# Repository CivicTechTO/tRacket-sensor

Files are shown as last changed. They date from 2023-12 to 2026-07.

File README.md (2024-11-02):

# tRacket: Community-Driven Urban Noise Monitoring

This repository contains all source code and hardware design files for the [tRacket](https://tracket.info/) noise sensor.

## Overview

Environmental noise, especially in urban settings, is a [known public health concern](https://www.toronto.ca/wp-content/uploads/2017/11/8f98-tph-How-Loud-is-Too-Loud-Health-Impacts-Environmental-Noise.pdf):

> The growing body of evidence indicates that exposure to excessive environmental
noise does not only impact quality of life and cause hearing loss but also has other health impacts, such as cardiovascular effects, cognitive impacts, sleep disturbance and mental health effects.

The tRacket noise sensor continuous monitors ambient sound levels (in [decibels](https://en.wikipedia.org/wiki/Decibel), dBA) and sends these measurements to an [online dashboard](https://dashboard.tracket.info/locations) ([also on GitHub](https://github.com/CivicTechTO/tRacket-dashboard)). Our goal is to help local communities better understand the sound levels and extreme noise events that they experience day to day.

The project has been started and is maintained by volunteers from the [CivicTech Toronto](http://www.civictech.ca) community.

## Privacy

We followed Privacy by Design principles in setting up the data collection. 

1. The sound meter devices are deployed on private properties in residential areas at different locations in the city. We are **not publishing exact device locations**. 
2. The devices **do not record sound** only sound levels in A-weighted decibel levels (dBA)(https://en.wikipedia.org/wiki/Decibel). 
3. We calculate minimum and maximum sound levels at 5 minute intervals on the device and **only broadcast these aggregate values** (along wiht the device ID) to a database.

## Source Code

The [noisemeter-device](/noisemeter-device) folder contains the device's source code, which is written in C++ and can be built using [PlatformIO](https://platformio.org/). Build instructions are available [in the online documentation](https://civictechto.github.io/tRacket-sensor/md_noisemeter_device_BUILD.html).

The source code is released under the [GNU GPL v3 license](/noisemeter-device/LICENSE).

## Hardware Files

The [hardware](/hardware) folder contains design files and documentation for each iteration of the sensor hardware. The PCBs are designed using [KiCAD](https://www.kicad.org/).

The hardware design files are released under an [open hardware license](/hardware/pcb-rev2/LICENSE).

## For Developers

* Check out the [Issues page](https://github.com/CivicTechTO/tRacket-sensor/issues) to see current bugs and feature requests. Any contributions are welcome!
* Online documentation of the firmware [is available here](https://civictechto.github.io/tRacket-sensor/).

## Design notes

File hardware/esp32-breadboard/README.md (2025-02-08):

# ESP32 Breadboard prototype

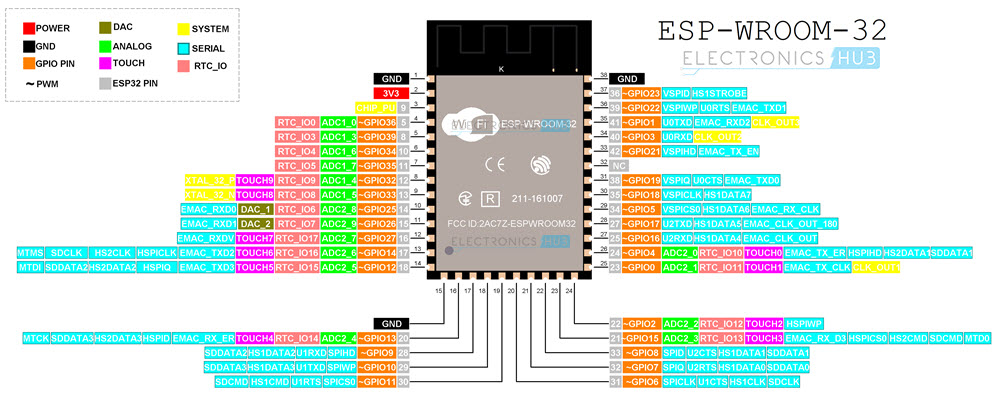
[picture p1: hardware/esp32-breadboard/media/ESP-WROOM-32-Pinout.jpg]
ESP32-WROOM Pinout


Board used (ESP32-WROOM): [https://a.co/d/6XwJp64](https://a.co/d/6XwJp64)

Mic module used (SPH0645LM4H): [https://www.adafruit.com/product/3421](https://www.adafruit.com/product/3421)

## Pin Connections:

| Mic  | Board |
| ---- | ----- |
| GND  | GND |
| BCLK | P23 |
| DOUT | P19 |
| LRCL | P18 |
| SEL  | GND |
| 3V | 3V |

| Misc  | Board |
| ----- | ----- |
| Reset | P5 |

> IMPORTANT - The I2S protocol is a 2-channel data stream. The SEL pin on the mic must be pulled LOW (to GND) in order to work with the example code, which reads data from the RIGHT CHANNEL only. Alternatively, the I2S driver can be set to read from left channel, although it remains unclear whether this would involve tying the SEL pin to 3.3V. If you get no appreciable readings (or all readings are the same as the MIC_NOISE_DB variable) then you may be reading the wrong channel, or you may need to check the SEL pin!

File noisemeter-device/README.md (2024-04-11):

# Noisemeter Device Firmware

This documentation is generated from the firmware's source code files. Modules of functionality are generally organized into classes; see the "Classes" tab to navigate their documentation. Other functions, constants, and variables can be found within the file list or via the search bar.

See "Related Pages" for other relevant documentation including build instructions and deprecated code.

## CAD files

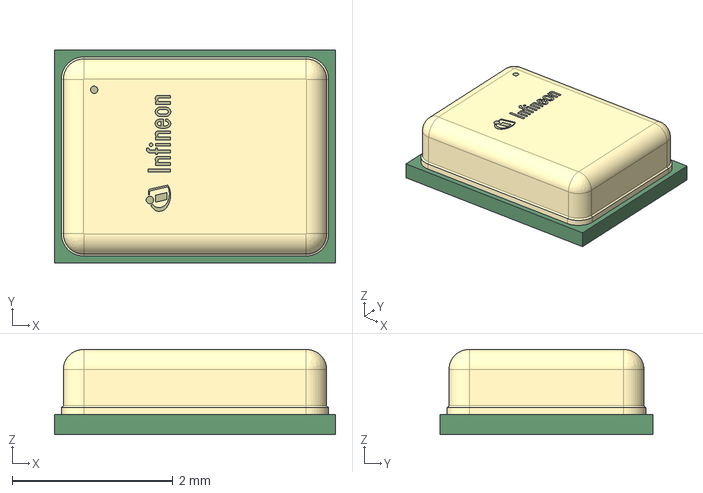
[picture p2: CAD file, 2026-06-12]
hardware/pcb-rev4/PG-TLGA-5-2_Z8B00234305_V05_3D.stp
3.50 x 2.65 x 1.06 mm

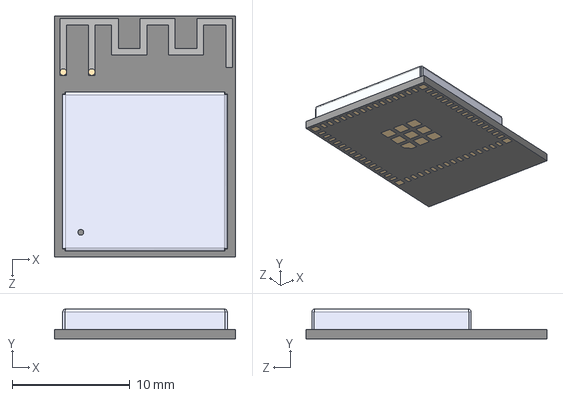
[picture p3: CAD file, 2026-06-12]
hardware/pcb-rev4/ESP32-S3-MINI-1-N8.STEP
15.4 x 2.55 x 20.5 mm

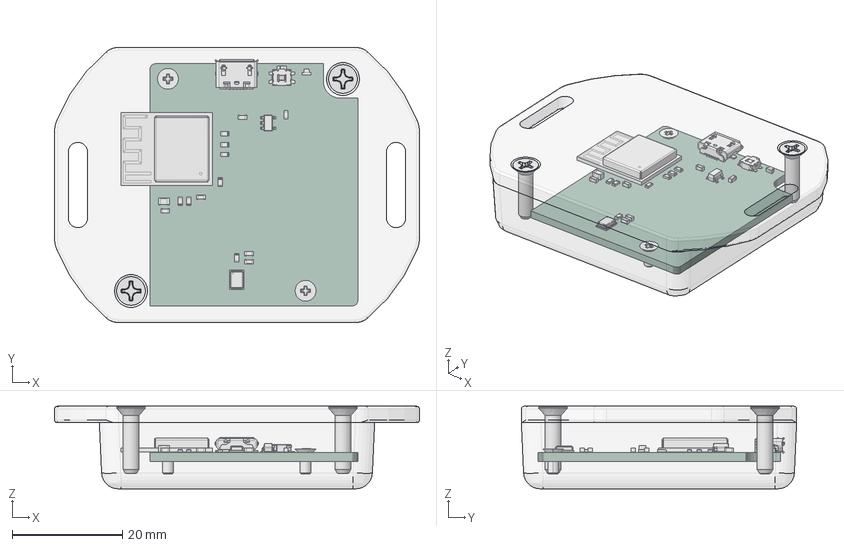
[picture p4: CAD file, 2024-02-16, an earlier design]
hardware/pcb-rev2/nmeter_cased.FCStd
66.3 x 50.0 x 15.0 mm
1551S Box
1551R-S Flange Lid
SC510 (screw #4X 1_2'' FH)
SC510 (screw #4X 1_2'' FH)001
_autosave-noisemeter PCB

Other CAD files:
hardware/pcb-rev3/tracket.FCStd

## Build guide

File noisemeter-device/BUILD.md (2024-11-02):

# Build Instructions

## Source code preparation

1. Save the SSL root certificate to `certs.h` using the following command:
```bash
python certs.py -s api.tracket.info > certs.h
```

## Code compilation and upload

1. [Install PlatformIO](https://platformio.org/install).

2. Run `pio run` to compile for the PCB. A breadboard target is available too: `pio run -e esp32-breadboard`.

3. Run `pio run -t upload` to upload to the device (this also compiles the code if there have been any changes).

## HMAC encryption key

Data stored on the device (e.g. WiFi credentials) are encrypted with an "eFuse" key. This key can only be configured once, and cannot be read or written after that. 

```bash
dd if=/dev/urandom of=hmac_key bs=1 count=32
pio pkg exec -- espefuse.py --port /dev/ttyACM0 burn_key BLOCK4 hmac_key HMAC_UP
rm hmac_key
```

This is done in the `bringup.sh` script that is used to program new sensors.

**Please generate a unique hmac_key for each device.**

## Enable secure download mode

Enabling secure download mode prevents users from using USB/serial download mode to dump memory contents (WiFi credentials and API token):

```bash
pio pkg exec -- espefuse.py --port /dev/ttyACM0 burn_efuse ENABLE_SECURE_DOWNLOAD
```

Then, if new firmware is to be uploaded over USB in the future, upload using this command:

```bash
pio pkg exec -- esptool.py write_flash 0x10000 .pio/build/esp32-pcb/firmware.bin
```

## Signing OTA updates

OTA updates must be signed for deployed tRacket sensors to accept them. The
GitHub repo is configured to automatically sign firmware updates when releases
are published.

Signing requires a 4096-bit RSA key. To sign an update (assuming you have the
private key), run `pio run -t ota`.

The public key is to be stored in `noisemeter_device/ota_update.cpp`. To obtain
the public key (assuming you have the private key), run:

```bash
openssl rsa -in priv_key.pem -pubout > rsa_key.pub
```

## Operation Overview:

* After initial programming or a factory reset, the device will enter Hotspot mode once it is powered on. This is indicated by a blinking LED.
* In Hotspot mode, you can connect to the device's "Noise meter" WiFi network to set it up. Password is "noisemeter".
* Once connected, a captive portal will bring you to a form to enter your WiFi credentials and email for registration. Your credentials will be encrypted and stored to the on-board flash memory.
* After completing the form, the device will reboot and attempt to connect to your WiFi.
* Once connected, the device will sync itself with a NTP time server and then begin taking readings.
* The device takes 100-millisecond audio recordings and instantly converts them to decibel "loudness" values. Each recording is discarded as soon as it is processed.
* Over time, the decibel values are aggregated into minimum, average, and maximum values. Periodically, these values will be uploaded to the server at which point the device will clear its cached data and begin taking a new set of readings.
* To factory reset the device and clear your saved credentials, hold the Reset button while you power on the device until the LED begins blinking.

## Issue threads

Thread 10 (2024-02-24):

Batch data uploading

tcsullivan, 2024-02-24:
The WiFi is intermittent on my balcony, so my device is sometimes unable to upload its latest min/max/average data. Currently we just discard the data point if the upload fails, but instead I think we should keep a list of previous data points that can be uploaded to the server later once the WiFi connection is restored.

The min/max/average data point is only a handful of bytes, so we are probably fine to just keep this list in RAM (*unless* we want to run devices long-term offline and bring them some WiFi every now and then to collect their data, which would require storing to flash). Let's make a list that can store data points that fail to upload and iterate through that list once we can successfully reach the server.

For this to be worthwhile, we'll want to implement #9 first.

tcsullivan, 2024-03-06:
The `timestamp` branch has batch uploading now. Keeps a `std::forward_list` of failed uploads and tries to send them all with each time interval. WiFi seems to reconnect automatically, but we also call `WiFi.reconnect()` before uploads to be safe.

Closed 2024-03-09.

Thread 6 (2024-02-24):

Encryption for stored information

tcsullivan, 2024-02-24:
The device stores the user's WiFi SSID, passkey, and device ID. The API token is in firmware too. Some or all of these should be encrypted for the sake of security.

The `encryption` branch has a simple implementation of AES encryption for the WiFi passkey. It uses the device's ID as an encryption key.

* What info should be encrypted?
* What should the encryption key be? How should the key be stored?

tcsullivan, 2024-03-15:
Let's just encrypt the WiFi credentials and the API token (as that will eventually be device-specific). I'm hoping we can find a hardware encryption feature that will make it difficult to extract these from a device.

tcsullivan, 2024-03-16:
Merged `main` into `encryption` to bring it up to date, and encrypted the SSID.

I don't know if there's anything we can do to make the encryption key truly "secret". The best solution I have is physical: If the reset button is not held down at startup, then immediately disconnect the serial/USB pins by setting pins 18 through 21 to OUTPUT. This way, we could limit a hacker's ability to dump the microcontroller's memory to decrypt our secrets.

tcsullivan, 2024-04-03:
I've discovered that we can use the HMAC with eFuse memory to do this encryption without exposing the key. Working on this now. Might also need to consider secure boot to fully ensure that a user can't extract the key or decrypted data.

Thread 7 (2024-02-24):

Over-the-Air (OTA) Updates

tcsullivan, 2024-02-24:
We want to be able to apply software updates to devices that are already deployed. Ideally, I think this should be automatic and more or less hidden from the user: every day or week check for an update from the server, and just apply it if available.

The `ota-support` branch has a proof-of-concept implemented. Some things to figure out:

* Hosting updates on the project's server
* Versioning of the updates (i.e. having "official" releases of updates)
* Can we sign the updates with a key to verify that they came from our server?
* Are there any other security considerations?

tcsullivan, 2024-03-15:
Let's look into using GitHub as the update host: maybe an Action can generate the latest firmware? An automated release?

How could we keep info on the latest version number...

tcsullivan, 2024-03-15:
I'm thinking too that the update checks should be run daily, as in 24 hours from the device's startup or last check. That will help stagger requests for update downloads.

tcsullivan, 2024-03-15:
Also, we'll want to make a note to update the HTTPS certificates between releases to prevent them from expiring.

tcsullivan, 2024-03-24:
Tested the 24hr timer on a rev2 PCB, it works!

Closed 2024-03-24.

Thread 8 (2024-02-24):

Prevent physical reprogramming

tcsullivan, 2024-02-24:
1. Disable the ESP32's programming interface. Changing the pin modes for the USB/serial pins may be enough; also need to check on bootloader settings. Actually committing to this change will require #7 first.
2. Consider flash encryption or other available options to disable readout. It looks like the ESP32's hardware encryption has [already been circumvented](https://hackaday.com/2024/01/15/breaking-the-flash-encryption-feature-of-espressifs-microcontrollers/), so I'm not sure we should bother with this.

tcsullivan, 2024-03-14:
This was my own idea, but after discussion we've agreed to let the devices be reprogrammable. All we really need to worry about is preventing reading/decrypting of secrets stored on the device.

tcsullivan, 2024-03-15:
Just noting the actual results of [the circumvention](https://courk.cc/breaking-flash-encryption-of-espressif-parts):

* Requires custom hardware and flash emulation to work
* Designed for *external* flash, while the MINI modules we're using are flash-in-chip. Would be much more difficult if not impossible to crack a module with this method.

Closed 2024-03-14.

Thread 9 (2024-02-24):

Generate timestamps on device

tcsullivan, 2024-02-24:
The data samples that get sent to the server should be timestamped on the device at the moment they are calculated, rather than relying on the server to timestamp the data whenever it receives it. Apparently the server already supports receiving timestamps (as a `timestamp` field within the JSON), so this should be easy to implement.

The server is flexible on the format of the timestamp, but let's stick to something standard.

tcsullivan, 2024-03-06:
This functionality is present in the `timestamp` branch now. Adding to the JSON was as easy as expected.

Closed 2024-03-09.

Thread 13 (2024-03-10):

Device setup form styling

tcsullivan, 2024-03-10:
Currently, the device setup form is just a super-simple request for WiFi credentials. Apart from functional improvements (email request, device ID reset option?), the form should also be styled better: colors, fonts maybe, project logo maybe, overall prettier presentation, and probably some user instructions/info.

The post-submission page should also give "next steps", noting that the device will restart and the Noisemeter WiFi will no longer be available.

Style recommendations or examples from web dev people are welcome: the device can present HTML, CSS, or even Javascript code to user's browser. It may be possible to store some small resources (icons, limited fonts) on the device, but the outside internet won't be available for external resources.

We'll also need to confirm that we're getting the information we need for the server/dashboard.

tcsullivan, 2024-03-11:
Tagged "good first issue" since this focuses on basic UI design and not much microcontroller programming.

tcsullivan, 2024-07-06:
Gabe put together styled webpages based on the main website's UI, they came out great. Just need to get a final OK on the implementation.

Closed 2024-09-08.

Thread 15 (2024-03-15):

Make device IDs based on MAC addresses

tcsullivan, 2024-03-15:
We're leaning towards having device IDs be generated from the device's MAC address, meaning a physical device will always have the same ID. The server can coordinate the linking of IDs to users.

The UUID library we're using can be seeded so that its generation isn't truly random. At that point, we may not need to bother with storing the UUID in "EEPROM" either.

Maybe the UUID format is not even necessary? Is it bad to expose our MAC addresses? Might want some input from cybersecurity people on this...

tcsullivan, 2024-03-24:
We could generate our own IDs and permanently store them in [eFuse](https://docs.espressif.com/projects/esp-idf/en/latest/esp32c3/api-reference/system/efuse.html) memory. Would just need a tool/script to generate new IDs and make sure they are always unique.

tcsullivan, 2024-03-26:
I've made the device ID a UUID generated from the device's MAC address which should be okay to start with. Still need to confirm if we should burn custom IDs instead.

Closed 2024-03-31.

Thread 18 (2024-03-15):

OTA Failsafe

tcsullivan, 2024-03-15:
Look into the possibility of recovering from a bad OTA update. Could we set up a bootloader or something that can run the OTA process without overwriting itself? Or could this bootloader host an access point for a user to upload a "recovery" update?

tcsullivan, 2024-03-15:
Check out [https://docs.espressif.com/projects/esp-idf/en/latest/esp32c3/api-reference/system/ota.html](https://docs.espressif.com/projects/esp-idf/en/latest/esp32c3/api-reference/system/ota.html): our platform already does this. Don't think there's anything else for us to do here.

Closed 2024-03-15.

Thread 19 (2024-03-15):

Batch upload indication

tcsullivan, 2024-03-15:
Say you set up a device in a remote location, configured for a WiFi hotspot that you bring to it daily to send its data to the server. How will the user know that the device has finally sent all of its data?

Since we kept an LED on the circuit board, I'm wondering if a blink pattern or something would be the easiest solution.

No milestone - this isn't a critical feature.

Closed 2024-04-02.

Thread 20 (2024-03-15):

New device registration and unique API tokens

tcsullivan, 2024-03-15:
How do we register new devices to the server?

* Probably need the server-side figured out first.
* Add email to setup form and store it in "EEPROM" once for initial reboot.
* Following reboot after setup, and successful WiFi connection, make a registration request with the device's ID and the user's email.
* Server will respond with a new API token for the device that we'll save (encrypted) to "EEPROM".

tcsullivan, 2024-04-04:
Waiting for API to support this.

tcsullivan, 2024-04-14:
API is ready - use `device/register` endpoint.

tcsullivan, 2024-05-19:
Implemented in the `new-api` branch.

Closed 2024-05-23.

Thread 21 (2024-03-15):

Access point: Create SSID dropdown instead of manual entry

tcsullivan, 2024-03-15:
1. ~~Create the access point in case the WiFi is not found after some amount of time.~~
2. Change SSID form field to a dropdown that's populated from [a network scan](https://github.com/espressif/arduino-esp32/tree/master/libraries/WiFi/examples/WiFiScan)? Would need to scan before entering AP mode I think...

tcsullivan, 2024-03-26:
Added WiFi connection timeout on the `onboarding-prep` branch.

tcsullivan, 2024-09-08:
More than one user has had issues with trying to connect to 5GHz WiFi networks; the ESP32 we're using unfortunately doesn't support these. If we can implement this dropdown, then that should ensure that users can only connect to compatible networks.

Closed 2025-01-18.

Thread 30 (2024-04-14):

Signed app verification

tcsullivan, 2024-04-14:
[https://docs.espressif.com/projects/esp-idf/en/latest/esp32c3/security/secure-boot-v2.html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](https://docs.espressif.com/projects/esp-idf/en/latest/esp32c3/security/secure-boot-v2.html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)

Build signature verification into the firmware so we can be certain that OTA updates will only occur with software we've released ourselves. This will be in lieu of full secure boot (at the moment), since we do not want to restrict users from reprogramming their devices themselves via USB.

tcsullivan, 2024-05-23:
This is now supported in the `new-api` branch. Since the "arduino" platform in PlatformIO doesn't really support a custom bootloader (required by the linked solution), signature verification will be done in the firmware after an update is downloaded.

Signing is done with a 4096-bit RSA key. The public key is kept in firmware, and OTA images have their signature stored in their first 512 bytes. Build hooks were added so that `pio run` produces a `firmware_signed.bin` file that can be uploaded directly to the server.

Closed 2024-05-23.

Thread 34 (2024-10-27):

Need good-looking 3D renders of the PCB and enclosure

tcsullivan, 2024-10-27:
The tRacket website needs updated images/renders of the device. This could be done in [Blender](https://www.blender.org/) or a similar software by anyone who has the experience (or wants to try!).

* The [homepage](https://tracket.info/) has a dark "tRacket" rectangle which could be replaced by a top-down view of the enclosure
* The [sensor page](https://tracket.info/sensor/) has a render of the rev. 2 PCB in the 3D-printed case. The style of the rendering is nice; the pictured hardware is just out-of-date.

This repo has a [FreeCAD](https://www.freecad.org/) project with a 3D model of the rev. 3 PCB and the enclosure here: [https://github.com/CivicTechTO/tRacket-sensor/blob/main/hardware/pcb-rev3/tracket.FCStd](https://github.com/CivicTechTO/tRacket-sensor/blob/main/hardware/pcb-rev3/tracket.FCStd)

If you are unable to use FreeCAD, let me know and we'll figure out how to get the files you need to get started.

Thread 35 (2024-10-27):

Research feasibility of solar power

tcsullivan, 2024-10-27:
The tRacket sensor currently depends on wired USB power. It would be massively beneficial if the sensor could be deployed long-term in locations where that isn't available; solar power seems like the most viable solution.

The sensor draws no more than 5V @ 100mA, and a quarter of that if WiFi is not running. Some ideas to look into:

* Solar panel options: USB panels? Solar harvesting circuits? How large of a panel do we need?
* Battery options: chemistry, capacity, size? A battery is necessary since the sensors run 24/7 and need energy when the sun is not out.
* Battery charger for storing excess solar energy into the battery
* PCB modifications: battery and/or solar panel connectors? Low-power microcontroller to minimize energy consumption when WiFi is not needed?
* Enclosure: Do we need a larger enclosure? How will the solar panel secure to it? More drilling for solar and battery connectors? Weatherproofing?
* How much will the solar-powered sensor cost?

I'll share more notes soon on the research I've done, but anyone is welcome to look into any of these points and share their findings here!

tcsullivan, 2024-11-02:
Ideally, we would redesign the sensor to be as low-power as possible, which would mean adding an ultra-low-power microcontroller for decibel monitoring as well as a solar harvester chip. Like these:

* Microcontroller: [STM32L431KB](https://www.digikey.ca/en/products/detail/stmicroelectronics/STM32L431KBU6TR/8257910)
* Harvester: [BQ25504](https://www.digikey.ca/en/products/detail/texas-instruments/BQ25504RGTR/2799286)

We should be able to get the sensor's average current consumption down to the milliwatt range, and the harvester would collect as much power as possible into a battery. We want to be able to charge the battery while also running the decibel monitoring, which would make that milliwatt target essential.

Also considering the solar panel and battery, taking this route would increase the sensor's cost by $20+ CAD.

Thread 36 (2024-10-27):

Test and calibrate decibel readings of fully assembled sensors

tcsullivan, 2024-10-27:
During development we tested the accuracy of decibel measurements from the bare sensor PCB, which proved the sensor to be accurate within a couple of decibels (dBA). However, once the PCB is assembled into the enclosure (including a layer of foam to protect the microphone), decibel readings appear to change. I'm not sure if this is just a linear shift in amplitude, or if the frequency response of the microphone has changed.

Ideally, we can do studio testing of the assembled sensor to fully validate this. Anyone with a couple of the sensors (one with enclosure and one without) can do basic testing of this too though: use a computer with PuTTY or minicom installed to view the serial output of the sensor over USB; this will show the dBA of every measurement taken. The serial port should be configured for 115200 baud.

If we can identify the discrepancy and make a software fix, that would be ideal. Otherwise, we'll need to look into foam selection and the size and placement of the microphone port to make the sensor as accurate as possible.

Let me know if you need to borrow PCBs to do this testing. Rev 2 or rev 3 PCBs with the 1551SFL enclosure should be used for this.

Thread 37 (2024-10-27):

Sensor packaging

tcsullivan, 2024-10-27:
We probably need packaging for when we begin distributing sensors. This would include an appropriately-sized box, maybe some bubble wrap, a printout of "get started" instructions, and a sticker to put on top of the box.

The assembled sensor is smaller than 3" x 3" x 1".

Staples has a cheap, small box: [Spicers Kraft Postal Box Peel & Seal Peel & Seal Small](https://www.staples.ca/products/3099025-en-spicers-kraft-postal-box-peel-seal-peel-seal-small-637-x-512-x-3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)

Please share any findings here if you look into this.

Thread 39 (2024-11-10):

Sensor Connectivity & Recovery Tests

danieltsoukup, 2024-11-10:
Goal: research & establish standard tests we can run on our sensors that ensure that connectivity is maintained/recovered after common network or software issues.

Issues can include but requires further research:
- sensor losing and regaining power,
- sensor losing network connection due to Wifi turned off, weak connection, etc.

Todo's:
- collect info from our current users on why sensors are going offline (could be a Slack thread)
- research IoT software testing
- plan for running these test in a reproducible manner: is there a software we can mock up a wifi host that can simulate such network issues?

danieltsoukup, 2025-01-11:
Notes from @gabesawhney :

The particular situation that I've observed is that sometimes when a sensor experiences a power outage, it doesn't successfully restart when power is restored. Manually power-cycling is all that's required to get it back online, but my hope would be that it comes back online by itself.

So tests might be:

    A: Power-cycle the device while watching the console, multiple times, maybe varying the length of the outage (and including super short outages)
    B: Power-cycle the device while watching the console, multiple times, where wifi is unavailable when power is restored (for a scenario where the AP takes longer to recover from the power outage than the sensor does, which seems likely)
    C: Power-cycle the device while watching the console, multiple times, where wifi is available when power is restored, but internet connectivity isn't (:shrug::skin-tone-4:)

We've talked about monitoring wifi signal strength, since at least some users have experienced challenges with low wifi signal strength (specifically in condos with thermal windows which, incidentally, block wifi). If/when
Clyne adds that code, we could run some tests to see how it performs in various conditions.

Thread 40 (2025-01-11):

Clip sensor reading values to non-negative

danieltsoukup, 2025-01-11:
We have seen recently that the sensor can produce invalid (negative) readings under certain extreme conditions (e.g., moisture saturating the mic) See https://dashboard.tracket.info/locations/747559 around January 1st.
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

The goal of this ticket is to adjust the sensor data processing to automatically clip values to be non-negative before sending to the API.

A related ticket is being worked on to notify sensor owners if the device is recording zeros, which should practically never happen https://github.com/CivicTechTO/tRacket-sensor-manager/issues/1

tcsullivan, 2025-01-18:
I made a new branch for this and added a lazy fix of forcing negative decibel values to zero before they are recorded. This made me come to a few realizations though:

1. Decibel measurements are the result of multiple "instantaneous" microphone samples. If one of these samples reads "zero", it is 99.99% likely to be invalid. Many zero samples in a row are what weigh dB values down to zero and below. Since this weighing down ruins accuracy, I wonder if any dB measurement should be zeroed if it contains an invalid sample? This would guarantee that only 100% valid (and accurate) measurements are recorded.

2. Maybe instead of zeroing an entire dB sample, we can just omit invalid mic samples from a dB calculation...

3. Should invalid/negative dB measurements (after being forced to zero) affect min/max/mean statistics? I think probably not, which means my lazy fix isn't enough.

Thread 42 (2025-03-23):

Automated sensor test on setup

danieltsoukup, 2025-03-23:
**Issue:**
How do we know that the sensor we received from the manufacturer is functional and our device setup steps (loading the firmware?) were correctly done.

**Proposal:**
Create an automate suite of tests that can be run when we set up sensors to check it can successfully connect to the wifi, make and send a measurement. At the end of testing, the sensor resets to its clean-slate status, ready to be shipped.

@tcsullivan @gabesawhney do we see the need for this?

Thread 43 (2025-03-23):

Concurrent API calls and measurements

danieltsoukup, 2025-03-23:
**Issue**
At the moment, when the sensor is sending measurements to the database, there are no noise measurements made which results in missing a few seconds of data.

**Proposal**
Explore options to make sure that the noise measurements do not stop while previous values are sent to the database.

tcsullivan, 2025-03-25:
The sensor firmware runs on top of a real-time operating system, FreeRTOS, which supports multi-threaded execution. I would propose having two threads, one that runs the decibel sampling and another which runs API calls every five minutes.

Some synchronization will be needed for the list of `DataPacket`s that are ready for upload.

tcsullivan, 2025-03-25:
The noise measurements should start as soon as possible too, no need to wait for the WiFi to connect. Of course, don't start the measurements if the device is unregistered (and may not be properly positioned then?).

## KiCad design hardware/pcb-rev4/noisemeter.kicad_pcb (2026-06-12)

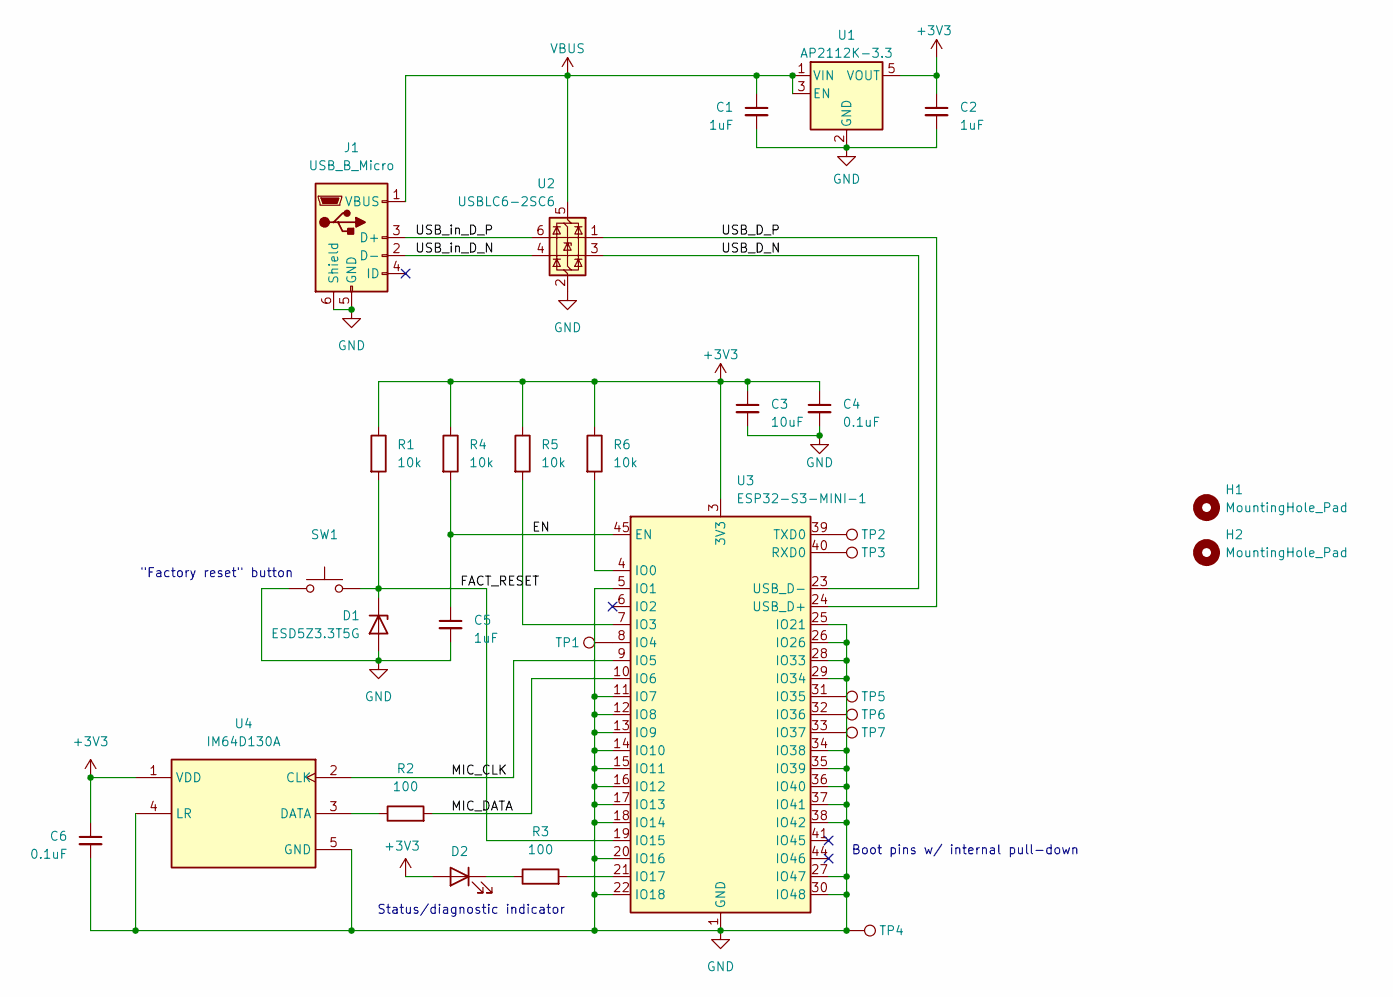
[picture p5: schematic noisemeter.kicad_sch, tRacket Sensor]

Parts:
C1, C2, C5: 1uF; C_0603_1608Metric; Part Number CC0603KRX7R7BB105
C3: 10uF; C_0805_2012Metric; Part Number CL21A106KOQNNNE
C4, C6: 0.1uF; C_0603_1608Metric; Part Number CC0603KRX7R6BB104
D1: ESD5Z3.3T5G; D_0603_1608Metric; Part Number ESD5Z3.3T5G
D2: LED; LED_0603_1608Metric; Part Number APT1608LVBC/D
H1, H2: MountingHole_Pad; MountingHole_2.5mm
J1: USB_B_Micro; USB_Micro-B_Molex_47346-0001; Part Number 0473460001
R1, R4, R5, R6: 10k; R_0603_1608Metric
R2, R3: 100; R_0603_1608Metric
SW1: SW_Push; SW_SPST_EVQP7C; Part Number EVQ-P7C01P
TP1, TP2, TP3, TP4, TP5, TP6, TP7: TestPoint; TestPoint_Pad_D1.0mm
U1: AP2112K-3.3; SOT-23-5; Part Number AP2112K-3.3TRG1
U2: USBLC6-2SC6; SOT-23-6; Part Number USBLC6-2SC6
U3: ESP32-S3-MINI-1; ESP32-S2-MINI-1; Part Number ESP32-S3-MINI-1-N8
U4: IM64D130A; IFX-PG-TLGA-5-6-V; Part Number IM64D130AXTMA1

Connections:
+3V3: C2.1, C3.1, C4.1, C6.1, D2.2 (A), R1.1, R4.1, R5.1, R6.1, U1.5 (VOUT), U3.3 (3V3), U4.1 (VDD)
/EN: C5.1, R4.2, U3.45 (EN)
/FACT_RESET: D1.1 (K), R1.2, SW1.1, U3.19 (IO15)
/MIC_CLK: U3.9 (IO5), U4.2 (CLK)
/MIC_DATA: R2.2, U3.10 (IO6)
/USB_D_N: U2.3 (I/O2), U3.23 (USB_D-)
/USB_D_P: U2.1 (I/O1), U3.24 (USB_D+)
/USB_in_D_N: J1.2 (D-), U2.4 (I/O2)
/USB_in_D_P: J1.3 (D+), U2.6 (I/O1)
GND: C1.2, C2.2, C3.2, C4.2, C5.2, C6.2, D1.2 (A), J1.5 (GND), J1.6 (Shield), SW1.2, TP4.1, U1.2 (GND), U2.2 (GND), U3.1 (GND), U3.2 (GND), U3.5 (IO1), U3.11 (IO7), U3.12 (IO8), U3.13 (IO9), U3.14 (IO10), U3.15 (IO11), U3.16 (IO12), U3.17 (IO13), U3.18 (IO14), U3.20 (IO16), U3.22 (IO18), U3.25 (IO21), U3.26 (IO26), U3.27 (IO47), U3.28 (IO33), U3.29 (IO34), U3.30 (IO48), U3.34 (IO38), U3.35 (IO39), U3.36 (IO40), U3.37 (IO41), U3.38 (IO42), U3.42 (GND), U3.43 (GND), U3.46 (GND), U3.47 (GND), U3.48 (GND), U3.49 (GND), U3.50 (GND), U3.51 (GND), U3.52 (GND), U3.53 (GND), U3.54 (GND), U3.55 (GND), U3.56 (GND), U3.57 (GND), U3.58 (GND), U3.59 (GND), U3.60 (GND), U3.61 (GND), U3.62 (GND), U3.63 (GND), U3.64 (GND), U3.65 (GND), U4.4 (LR), U4.5 (GND)
unnamed: D2.1 (K), R3.1
unnamed: R6.2, U3.4 (IO0)
unnamed: R5.2, U3.7 (IO3)
unnamed: TP1.1, U3.8 (IO4)
unnamed: R3.2, U3.21 (IO17)
unnamed: TP5.1, U3.31 (IO35)
unnamed: TP6.1, U3.32 (IO36)
unnamed: TP7.1, U3.33 (IO37)
unnamed: TP3.1, U3.40 (RXD0)
unnamed: TP2.1, U3.39 (TXD0)
unnamed: R2.1, U4.3 (DATA)
VBUS: C1.1, J1.1 (VBUS), U1.1 (VIN), U1.3 (EN), U2.5 (VBUS)

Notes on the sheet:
Status/diagnostic indicator
Boot pins w/ internal pull-down
"Factory reset" button

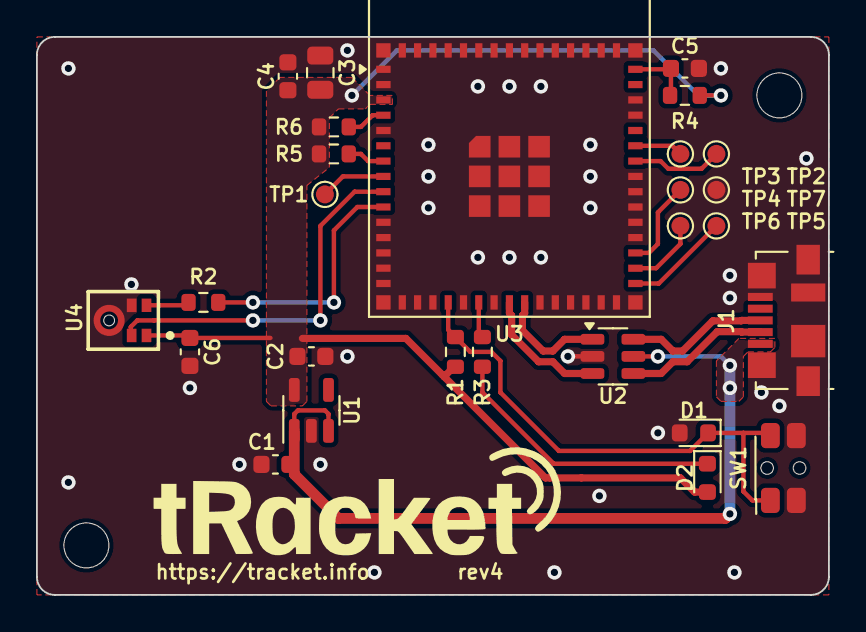
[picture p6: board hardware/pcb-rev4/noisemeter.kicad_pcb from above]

Board: 2 copper layers, 44.0 x 31.0 mm, 29 parts (0 on the bottom side), 22 nets.

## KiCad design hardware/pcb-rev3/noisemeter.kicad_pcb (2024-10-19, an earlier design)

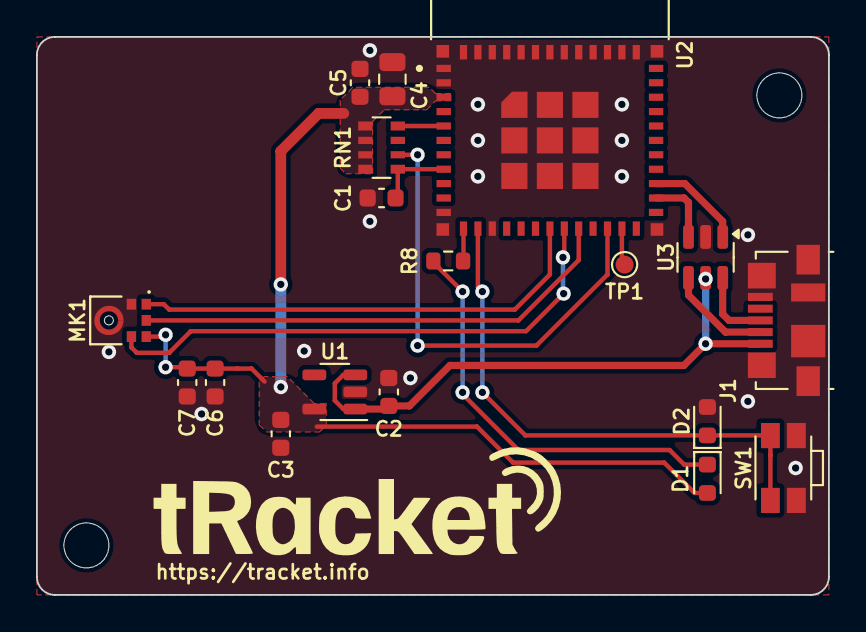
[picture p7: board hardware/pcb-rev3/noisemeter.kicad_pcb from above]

Board: 2 copper layers, 44.0 x 31.0 mm, 20 parts (0 on the bottom side), 17 nets.

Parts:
C1, C2, C3: 1uF; C_0603_1608Metric
C4: 10uF; C_0805_2012Metric
C5, C6: 0.1uF; C_0603_1608Metric
C7: 200pF; C_0603_1608Metric
D1: LED; LED_0603_1608Metric
D2: ESD5Z3.3T5G; D_0603_1608Metric
H1, H2: MountingHole_Pad; MountingHole_2.5mm
J1: USB_B_Micro; USB_Micro-B_Molex_47346-0001
MK1: SPH0645LM4H-B; MIC_SPH0645LM4H-B
R8: 51; R_0603_1608Metric
RN1: 10k; R_Array_Convex_4x0603
SW1: SW_Push; SW_SPST_EVQP7A
TP1: TestPoint; TestPoint_Pad_D1.0mm
U1: AP2112K-3.3; SOT-23-5
U2: ESP32-C3-MINI-1-N4; XCVR_ESP32-C3-MINI-1-N4
U3: USBLC6-2SC6; SOT-23-6

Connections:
+3V3: C3.1, C4.1, C5.1, C6.1, C7.1, D1.2 (A), MK1.5 (VDD), RN1.5 (R4.2), RN1.6 (R3.2), RN1.7 (R2.2), RN1.8 (R1.2), U1.5 (VOUT), U2.3 (3V3)
FACT_RESET: D2.1 (K), SW1.1, U2.13 (IO1)
GND: C1.2, C2.2, C3.2, C4.2, C5.2, C6.2, C7.2, D2.2 (A), J1.5 (GND), J1.6 (Shield), MK1.2 (SELECT), MK1.3 (GND), SW1.2, U1.2 (GND), U2.1 (GND), U2.2 (GND), U2.11 (GND), U2.14 (GND), U2.36 (GND), U2.37 (GND), U2.38 (GND), U2.39 (GND), U2.40 (GND), U2.41 (GND), U2.42 (GND), U2.43 (GND), U2.44 (GND), U2.45 (GND), U2.46 (GND), U2.47 (GND), U2.48 (GND), U2.49_1 (GND), U2.49_2 (GND), U2.49_3 (GND), U2.49_4 (GND), U2.49_5 (GND), U2.49_6 (GND), U2.49_7 (GND), U2.49_8 (GND), U2.49_9 (GND), U2.50 (GND), U2.51 (GND), U2.52 (GND), U2.53 (GND), U3.2 (GND)
IO2: RN1.4 (R4.1), U2.5 (IO2)
IO8: RN1.2 (R2.1), U2.22 (IO8)
MIC_BCLK: MK1.4 (BCLK), U2.19 (IO5)
MIC_DATA_OUT: MK1.6 (DATA_OUT), U2.20 (IO6)
MIC_WS: MK1.1 (WS), U2.18 (IO4)
unnamed: D1.1 (K), R8.2
unnamed: C1.1, RN1.1 (R1.1), U2.8 (EN)
unnamed: TP1.1, U2.23 (IO9)
STAT_LED: R8.1, U2.12 (IO0)
USB_D_N: U2.26 (IO18), U3.3 (I/O2)
USB_D_P: U2.27 (IO19), U3.1 (I/O1)
USB_in_D_N: J1.2 (D-), U3.4 (I/O2)
USB_in_D_P: J1.3 (D+), U3.6 (I/O1)
VBUS: C2.1, J1.1 (VBUS), U1.1 (VIN), U1.3 (EN), U3.5 (VBUS)

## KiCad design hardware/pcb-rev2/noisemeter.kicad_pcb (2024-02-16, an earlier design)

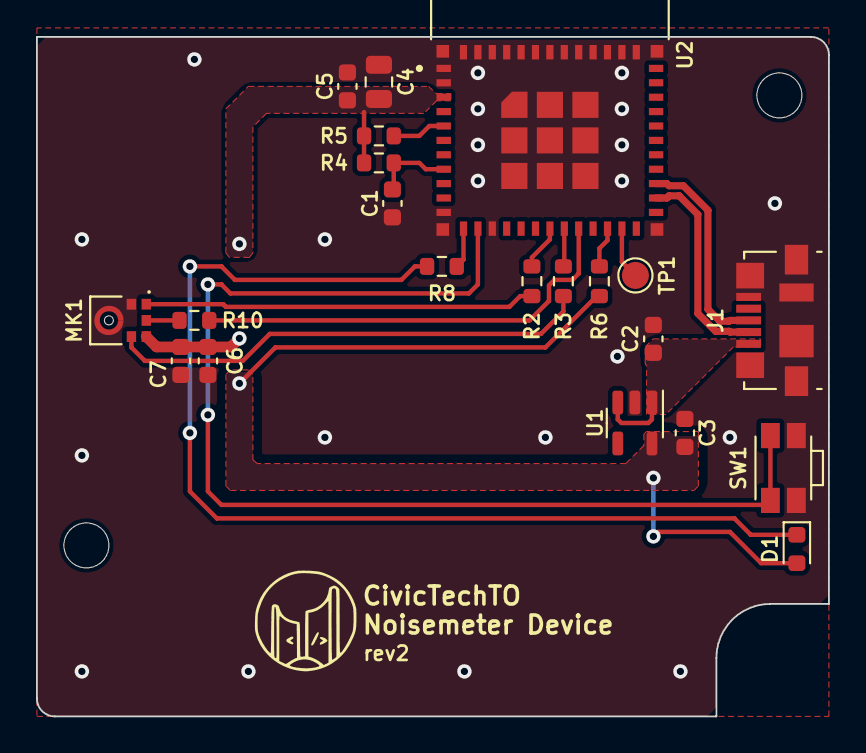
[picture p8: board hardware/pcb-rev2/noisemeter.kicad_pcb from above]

Board: 2 copper layers, 44.0 x 37.8 mm, 23 parts (0 on the bottom side), 18 nets.

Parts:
C1, C2, C3: 1U; C_0603_1608Metric
C4: 10U; C_0805_2012Metric
C5, C6: 0.1U; C_0603_1608Metric
C7: 200P; C_0603_1608Metric
D1: LED; LED_0603_1608Metric
H1, H2: MountingHole_Pad; MountingHole_2.5mm
J1: USB_B_Micro; USB_Micro-B_Molex_47346-0001
MK1: SPH0645LM4H-B; MIC_SPH0645LM4H-B
R2, R3, R8, R10: 51; R_0603_1608Metric
R4, R5, R6: 10K; R_0603_1608Metric
SW1: SW_Push; SW_SPST_EVQP7A
TP1: TestPoint; TestPoint_Pad_D1.5mm
U1: AP2112K-3.3; SOT-23-5
U2: ESP32-C3-MINI-1-N4; XCVR_ESP32-C3-MINI-1-N4

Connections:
+3V3: C3.1, C4.1, C5.1, C6.1, C7.1, D1.2 (A), MK1.5 (VDD), R4.2, R5.2, R6.2, U1.5 (VOUT), U2.3 (3V3)
FACT_RESET: SW1.1, U2.13 (IO1)
GND: C1.2, C2.2, C3.2, C4.2, C5.2, C6.2, C7.2, J1.5 (GND), J1.6 (Shield), MK1.2 (SELECT), MK1.3 (GND), SW1.2, U1.2 (GND), U2.1 (GND), U2.2 (GND), U2.11 (GND), U2.14 (GND), U2.36 (GND), U2.37 (GND), U2.38 (GND), U2.39 (GND), U2.40 (GND), U2.41 (GND), U2.42 (GND), U2.43 (GND), U2.44 (GND), U2.45 (GND), U2.46 (GND), U2.47 (GND), U2.48 (GND), U2.49_1 (GND), U2.49_2 (GND), U2.49_3 (GND), U2.49_4 (GND), U2.49_5 (GND), U2.49_6 (GND), U2.49_7 (GND), U2.49_8 (GND), U2.49_9 (GND), U2.50 (GND), U2.51 (GND), U2.52 (GND), U2.53 (GND)
IO2: R5.1, U2.5 (IO2)
IO8: R6.1, U2.22 (IO8)
MIC_BCLK: MK1.4 (BCLK), R3.1
MIC_DATA_OUT: R10.2, U2.20 (IO6)
MIC_WS: MK1.1 (WS), R2.1
unnamed: D1.1 (K), R8.2
unnamed: MK1.6 (DATA_OUT), R10.1
unnamed: C1.1, R4.1, U2.8 (EN)
unnamed: R2.2, U2.18 (IO4)
unnamed: R3.2, U2.19 (IO5)
unnamed: TP1.1, U2.23 (IO9)
STAT_LED: R8.1, U2.12 (IO0)
USB_D_N: J1.2 (D-), U2.26 (IO18)
USB_D_P: J1.3 (D+), U2.27 (IO19)
VBUS: C2.1, J1.1 (VBUS), U1.1 (VIN), U1.3 (EN)

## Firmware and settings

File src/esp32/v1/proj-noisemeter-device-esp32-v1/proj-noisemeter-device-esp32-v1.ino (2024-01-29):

/**
 * Civic Tech TO - Noisemeter Device (ESP32 Version) v1
 * Written by Clyne Sullivan and Nick Barnard.
 * Open source dB meter code taken from Ivan Kostoski (https://github.com/ikostoski/esp32-i2s-slm)
 * 
 * TODO:
 *  - Use DNS to make a "captive portal" that brings users directly to the credentials form.
 *  - Encrypt the stored credentials (simple XOR with a long key?).
 *  - Add second step to Access Point flow - to gather users email, generate a UUID and upload them to the cloud. UUID to be saved in EEPROM
 *  - Add functionality to reset the device periodically (eg every 24 hours)
 *  - 
 */
#include <ArduinoJson.h>  // https://arduinojson.org/
#include <ArduinoJson.hpp>
#include <WiFi.h>
#include <WiFiMulti.h>
#include <CRC32.h>  // https://github.com/bakercp/CRC32
#include <EEPROM.h>
#include <WebServer.h>
#include <WiFiAP.h>
#include <HTTPClient.h>
#include <WiFiClientSecure.h>
#include <dummy.h>       // ESP32 core
#include <driver/i2s.h>  // ESP32 core

#include "sos-iir-filter.h"
#include "certs.h"
#include "secret.h"

#include <cstdint>

WiFiMulti WiFiMulti;

constexpr auto AccessPointSSID = "Noise meter";
constexpr auto AccessPointPsk = "noisemeter";
const bool UPLOAD_DISABLED = false;
const unsigned long UPLOAD_INTERVAL_MS = 60000 * 5;  // Upload every 5 mins
// const unsigned long UPLOAD_INTERVAL_MS = 30000;  // Upload every 30 secs
const String DEVICE_ID = "nickjan2024int";  // TODO EPROM
const unsigned long MIN_READINGS_BEFORE_UPLOAD = 20;

// The ESP32's IP address within its access point will be "4.3.2.1".
// Once connected to the access point, open up 4.3.2.1 in a browser to get
// to the credentials form.
static const IPAddress AccessPointIP(4, 3, 2, 1);

//
// Constants & Config
//
#define LEQ_PERIOD 1         // second(s)
#define WEIGHTING A_weighting  // Also avaliable: 'C_weighting' or 'None' (Z_weighting)
#define LEQ_UNITS "LAeq"       // customize based on above weighting used
#define DB_UNITS "dBA"         // customize based on above weighting used
#define USE_DISPLAY 0

// NOTE: Some microphones require at least DC-Blocker filter
#define MIC_EQUALIZER SPH0645LM4H_B_RB  // See below for defined IIR filters or set to 'None' to disable
#define MIC_OFFSET_DB 0            // Default offset (sine-wave RMS vs. dBFS). Modify this value for linear calibration

// Customize these values from microphone datasheet
#define MIC_SENSITIVITY -26    // dBFS value expected at MIC_REF_DB (Sensitivity value from datasheet)
#define MIC_REF_DB 94.0        // Value at which point sensitivity is specified in datasheet (dB)
#define MIC_OVERLOAD_DB 120.0  // dB - Acoustic overload point
#define MIC_NOISE_DB 29        // dB - Noise floor
#define MIC_BITS 24            // valid number of bits in I2S data
#define MIC_CONVERT(s) (s >> (SAMPLE_BITS - MIC_BITS))
#define MIC_TIMING_SHIFT 0  // Set to one to fix MSB timing for some microphones, i.e. SPH0645LM4H-x

// Calculate reference amplitude value at compile time
constexpr double MIC_REF_AMPL = pow(10, double(MIC_SENSITIVITY) / 20) * ((1 << (MIC_BITS - 1)) - 1);

//
// Sampling
//
#define SAMPLE_RATE 48000  // Hz, fixed to design of IIR filters
#define SAMPLE_BITS 32     // bits
#define SAMPLE_T int32_t
#define SAMPLES_SHORT (SAMPLE_RATE / 8)  // ~125ms
#define SAMPLES_LEQ (SAMPLE_RATE * LEQ_PERIOD)
#define DMA_BANK_SIZE (SAMPLES_SHORT / 16)
#define DMA_BANKS 32

// Data we push to 'samples_queue'
struct sum_queue_t {
  // Sum of squares of mic samples, after Equalizer filter
  float sum_sqr_SPL;
  // Sum of squares of weighted mic samples
  float sum_sqr_weighted;
};

// Static buffer for block of samples
float samples[SAMPLES_SHORT] __attribute__((aligned(4)));

// Grounding this pin (e.g. with a button) will force access open to start.
// Useful as a "reset" button to overwrite currently saved credentials.
#define CredsResetPin 5
//
// I2S pins - Can be routed to almost any (unused) ESP32 pin.
//            SD can be any pin, inlcuding input only pins (36-39).
//            SCK (i.e. BCLK) and WS (i.e. L/R CLK) must be output capable pins
//
// Below ones are just example for my board layout, put here the pins you will use
//
#define I2S_WS 18
#define I2S_SCK 23
#define I2S_SD 19
// I2S peripheral to use (0 or 1)
#define I2S_PORT I2S_NUM_0

// EEPROM addresses for credential data.
constexpr unsigned int EEPROMMaxStringSize = 64;
constexpr int EEPROMEntryCSum = 0;  // CRC32 checksum of SSID and passkey
constexpr int EEPROMEntrySSID = EEPROMEntryCSum + sizeof(uint32_t);
constexpr int EEPROMEntryPsk = EEPROMEntrySSID + EEPROMMaxStringSize;
constexpr int EEPROMTotalSize = EEPROMEntryPsk + EEPROMMaxStringSize;

// Not sure if WiFiClientSecure checks the validity date of the certificate.
// Setting clock just to be sure...
void setClock() {
  configTime(0, 0, "pool.ntp.org");

  Serial.print(F("Waiting for NTP time sync: "));
  time_t nowSecs = time(nullptr);
  while (nowSecs < 8 * 3600 * 2) {
    delay(500);
    Serial.print(F("."));
    yield();
    nowSecs = time(nullptr);
  }

  Serial.println();
  struct tm timeinfo;
  gmtime_r(&nowSecs, &timeinfo);
  Serial.print(F("Current time: "));
  Serial.print(asctime(&timeinfo));
}

// Main webpage HTML with form to collect WiFi credentials.
static const char SetupPageHTML[] PROGMEM = R"(
<!DOCTYPE html>
<html lang='en'>
<head>
  <meta charset='utf-8'>
  <meta name='viewport' content='width=device-width,initial-scale=1'/>
</head>
<body>
<h1>Noise Meter Setup</h1>
<form method='POST' action='' enctype='multipart/form-data'>
<p>SSID:</p>
<input type='text' name='ssid'>
<p>Password:</p>
<input type='password' name='psk'>
<input type='submit' value='Connect'>
</form>
</body>
</html>
)";

// HTML to show after credentials are submitted.
static const char SubmitPageHTML[] PROGMEM = R"(
<!DOCTYPE html>
<html lang='en'>
<head>
  <meta charset='utf-8'>
  <meta name='viewport' content='width=device-width,initial-scale=1'/>
</head>
<body>
<h1>Noise Meter Setup</h1>
<p>Connecting...</p>
</body>
</html>
)";

/**
 * Starts the WiFi access point and web server and enters an infinite loop to process connections.
 */
[[noreturn]] static void runAccessPoint();

/**
 * Calculates a CRC32 checksum based on the given SSID and passkey.
 * Checksums are used to determine if the credentials in EEPROM are valid.
 */
static uint32_t calculateCredsChecksum(const String& ssid, const String& psk);

/**
 * Prints the SSID and passkey to Serial.
 */
static void printCredentials(const String& ssid, const String& psk);

/**
 * Saves credentials to EEPROM is form was properly submitted.
 * If successful, reboots the microcontroller.
 */
static void saveNetworkCreds(WebServer& httpServer);

/**
 * Returns true if the credentials stored in EEPROM are valid.
 */
static bool isEEPROMCredsValid();

/**
 * Returns true if the "reset" button is pressed, meaning the user wants to input new credentials.
 */
static bool isCredsResetPressed();

// Sampling Buffers & accumulators
sum_queue_t q;
uint32_t Leq_samples = 0;
double Leq_sum_sqr = 0;
double Leq_dB = 0;
size_t bytes_read = 0;

// Noise Level Readings
int numberOfReadings = 0;
float minReading = MIC_OVERLOAD_DB;
float maxReading = MIC_NOISE_DB;
float sumReadings = 0;
unsigned long lastUploadMillis = 0;

/**
 * Initialization routine.
 */
void setup() {
  // If needed, now you can actually lower the CPU frquency,
  // i.e. if you want to (slightly) reduce ESP32 power consumption
  // setCpuFrequencyMhz(80);  // It should run as low as 80MHz

  Serial.begin(115200);
  Serial.println();
  Serial.println("Initializing...");

  EEPROM.begin(EEPROMTotalSize);
  delay(2000);  // Ensure the EEPROM peripheral has enough time to initialize.

  initMicrophone();

  if (!UPLOAD_DISABLED) {
    // Run the access point if it is requested or if there are no valid credentials.
    if (isCredsResetPressed() || !isEEPROMCredsValid()) {
      eraseNetworkCreds();
      runAccessPoint();
    }

    // Valid credentials: Next step would be to connect to the network.
    const auto ssid = EEPROM.readString(EEPROMEntrySSID);
    const auto psk = EEPROM.readString(EEPROMEntryPsk);

    Serial.print("Ready to connect to ");
    printCredentials(ssid, psk);

    int ssid_len = ssid.length() + 1;
    int psk_len = psk.length() + 1;

    char intSSID[ssid_len];
    char intPSK[psk_len];
    ssid.toCharArray(intSSID, ssid_len);
    psk.toCharArray(intPSK, psk_len);

    WiFi.mode(WIFI_STA);
    WiFiMulti.addAP(intSSID, intPSK);


    // wait for WiFi connection
    Serial.print("Waiting for WiFi to connect...");
    while ((WiFiMulti.run() != WL_CONNECTED)) {
      Serial.print(".");
      delay(500);
    }
    Serial.println("\nConnected to the WiFi network");
    Serial.print("Local ESP32 IP: ");
    Serial.println(WiFi.localIP());

    setClock();
  }
}

void loop() {


  readMicrophoneData();

  if (canUploadData()) {
    WiFiClientSecure* client = new WiFiClientSecure;
    float average = sumReadings / numberOfReadings;
    String payload = createJSONPayload(DEVICE_ID, minReading, maxReading, average);
    uploadData(client, payload);
    delete client;
  };
}

void runAccessPoint() {
  static WebServer httpServer(80);

  WiFi.mode(WIFI_AP);
  WiFi.softAPConfig(AccessPointIP, AccessPointIP, IPAddress(255, 255, 255, 0));
  WiFi.softAP(AccessPointSSID, AccessPointPsk);

  // GET request means user wants to see the form.
  // POST request means user has submitted data through the form.
  httpServer.on("/", HTTP_GET,
                [] {
                  httpServer.send_P(200, PSTR("text/html"), SetupPageHTML);
                });
  httpServer.on("/", HTTP_POST,
                [] {
                  // Show "submitted" page immediately before we begin saving the credentials.
                  httpServer.client().setNoDelay(true);
                  httpServer.send_P(200, PSTR("text/html"), SubmitPageHTML);
                  saveNetworkCreds(httpServer);
                });
  httpServer.begin();

  Serial.println("Running setup access point.");

  while (1)
    httpServer.handleClient();
}

void printCredentials(const String& ssid, const String& psk) {
  Serial.print("SSID \"");
  Serial.print(ssid);
  Serial.print("\" passkey \"");
  Serial.print(psk);
  Serial.println("\"");
}

void printArray(float arr[], unsigned long length) {
  Serial.print(length);
  Serial.print(" {");
  for (int i = 0; i < length; i++) {
    Serial.print(arr[i]);
    if (i < length - 1) Serial.print(", ");
  }
  Serial.println("}");
}

void printReadingToConsole(double reading) {
  String output = "";
  output += reading;
  output += "dB";
  if (numberOfReadings > 1) {
    output += " [+" + String(numberOfReadings - 1) + " more]";
  }
  Serial.println(output);
}

uint32_t calculateCredsChecksum(const String& ssid, const String& psk) {
  CRC32 crc;
  crc.update(ssid.c_str(), ssid.length());
  crc.update(psk.c_str(), psk.length());
  return crc.finalize();
}

bool isEEPROMCredsValid() {
  const auto csum = EEPROM.readUInt(EEPROMEntryCSum);
  const auto ssid = EEPROM.readString(EEPROMEntrySSID);
  const auto psk = EEPROM.readString(EEPROMEntryPsk);

  Serial.print("EEPROM stored credentials: ");
  printCredentials(ssid, psk);

  return !ssid.isEmpty() && !psk.isEmpty() && csum == calculateCredsChecksum(ssid, psk);
}

bool isCredsResetPressed() {
  pinMode(CredsResetPin, INPUT_PULLUP);
  delay(100);  // Let the IO circuit settle.
  Serial.println();
  Serial.print("Is reset detected: ");
  Serial.println(!digitalRead(CredsResetPin));
  return !digitalRead(CredsResetPin);
}

void saveNetworkCreds(WebServer& httpServer) {
  // Confirm that the form was actually submitted.
  if (httpServer.hasArg("ssid") && httpServer.hasArg("psk")) {
    const auto ssid = httpServer.arg("ssid");
    const auto psk = httpServer.arg("psk");

    // Confirm that the given credentials will fit in the allocated EEPROM space.
    if (ssid.length() < EEPROMMaxStringSize && psk.length() < EEPROMMaxStringSize) {
      EEPROM.writeUInt(EEPROMEntryCSum, calculateCredsChecksum(ssid, psk));
      EEPROM.writeString(EEPROMEntrySSID, ssid);
      EEPROM.writeString(EEPROMEntryPsk, psk);
      EEPROM.commit();

      Serial.print("Saving ");
      printCredentials(ssid, psk);

      Serial.println("Saved network credentials. Restarting...");
      delay(2000);
      ESP.restart();  // Software reset.
    }
  }

  // TODO inform user that something went wrong...
  Serial.println("Error: Invalid network credentials!");
}

void eraseNetworkCreds() {
  Serial.println("Erasing stored credentials...");
  EEPROM.writeUInt(EEPROMEntryCSum, calculateCredsChecksum("", ""));
  EEPROM.writeString(EEPROMEntrySSID, "");
  EEPROM.writeString(EEPROMEntryPsk, "");
  EEPROM.commit();
  Serial.println("Erase complete");

  const auto ssid = EEPROM.readString(EEPROMEntrySSID);
  const auto psk = EEPROM.readString(EEPROMEntryPsk);
  Serial.print("Stored Credentials after erasing: ");
  printCredentials(ssid, psk);
  delay(2000);
}

String createJSONPayload(String deviceId, float min, float max, float average) {
  DynamicJsonDocument doc(2048);
  doc["parent"] = "/Bases/nm1";
  doc["data"]["type"] = "comand";
  doc["data"]["version"] = "1.0";
  doc["data"]["contents"][0]["Type"] = "Noise";
  doc["data"]["contents"][0]["Min"] = min;
  doc["data"]["contents"][0]["Max"] = max;
  doc["data"]["contents"][0]["Mean"] = average;
  doc["data"]["contents"][0]["DeviceID"] = deviceId;  // TODO

  // Serialize JSON document
  String json;
  serializeJson(doc, json);
  return json;
}

bool canUploadData() {
  // DEBUG SWITCH - If true, will skip upload and continue accumulating data
  if (UPLOAD_DISABLED) return false;

  // Has it been at least the upload interval since we uploaded data?
  long now = millis();
  long msSinceLastUpload = now - lastUploadMillis;
  if (msSinceLastUpload < UPLOAD_INTERVAL_MS) return false;

  // Do we have the minimum number of readings stored to form a resonable average?
  if (numberOfReadings < MIN_READINGS_BEFORE_UPLOAD) return false;
  return true;
}

void uploadData(WiFiClientSecure* client, String json) {
  if (client) {
    client->setCACert(cert_ISRG_Root_X1);
    {
      // Add a scoping block for HTTPClient https to make sure it is destroyed before WiFiClientSecure *client is
      HTTPClient https;
      // void addHeader(const String& name, const String& value, bool first = false, bool replace = true);

      Serial.print("[HTTPS] begin...\n");
      if (https.begin(*client, "https://noisemeter.webcomand.com/ws/put")) {  // HTTPS
        Serial.print("[HTTPS] POST...\n");
        // start connection and send HTTP header


        // void addHeader(const String& name, const String& value, bool first = false, bool replace = true);
        https.addHeader("Authorization", String("Token ") + API_TOKEN);
        https.addHeader("Content-Type", "application/json");
        https.addHeader("Content-Length", String(json.length()));
        https.addHeader("User-Agent", "ESP32");

        int httpCode = https.POST(json);
        // int POST(uint8_t * payload, size_t size);
        // int POST(String payload);

        // httpCode will be negative on error
        if (httpCode > 0) {
          // HTTP header has been send and Server response header has been handled
          Serial.printf("[HTTPS] POST... code: %d\n", httpCode);

          // file found at server
          if (httpCode == HTTP_CODE_OK || httpCode == HTTP_CODE_MOVED_PERMANENTLY) {
            String payload = https.getString();
            Serial.println(payload);
          }
        } else {
          Serial.printf("[HTTPS] POST... failed, error: %s\n", https.errorToString(httpCode).c_str());
        }

        https.end();
      } else {
        Serial.printf("[HTTPS] Unable to connect\n");
      }

      // End extra scoping block
    }

    // delete client;
  } else {
    Serial.println("Unable to create client");
  }

  long now = millis();
  lastUploadMillis = now;
  resetReading();
};  // Given a serialized JSON payload, upload the data to webcomand

void resetReading() {
  Serial.println("Resetting readings cache...");
  numberOfReadings = 0;
  minReading = MIC_OVERLOAD_DB;
  maxReading = MIC_NOISE_DB;
  sumReadings = 0;
  Serial.println("Reset complete");
};

//
// I2S Microphone sampling setup
//
void mic_i2s_init() {
  // Setup I2S to sample mono channel for SAMPLE_RATE * SAMPLE_BITS
  // NOTE: Recent update to Arduino_esp32 (1.0.2 -> 1.0.3)
  //       seems to have swapped ONLY_LEFT and ONLY_RIGHT channels
  const i2s_config_t i2s_config = {
    mode: i2s_mode_t(I2S_MODE_MASTER | I2S_MODE_RX),
    sample_rate: SAMPLE_RATE,
    bits_per_sample: i2s_bits_per_sample_t(SAMPLE_BITS),
    channel_format: I2S_CHANNEL_FMT_ONLY_RIGHT,
    communication_format: i2s_comm_format_t(I2S_COMM_FORMAT_I2S | I2S_COMM_FORMAT_I2S_MSB),
    intr_alloc_flags: ESP_INTR_FLAG_LEVEL1,
    dma_buf_count: DMA_BANKS,
    dma_buf_len: DMA_BANK_SIZE,
    use_apll: true,
    tx_desc_auto_clear: false,
    fixed_mclk: 0
  };
  // I2S pin mapping
  const i2s_pin_config_t pin_config = {
    bck_io_num: I2S_SCK,
    ws_io_num: I2S_WS,
    data_out_num: -1,  // not used
    data_in_num: I2S_SD
  };

  i2s_driver_install(I2S_PORT, &i2s_config, 0, NULL);

#if (MIC_TIMING_SHIFT > 0)
  // Undocumented (?!) manipulation of I2S peripheral registers
  // to fix MSB timing issues with some I2S microphones
  REG_SET_BIT(I2S_TIMING_REG(I2S_PORT), BIT(9));
  REG_SET_BIT(I2S_CONF_REG(I2S_PORT), I2S_RX_MSB_SHIFT);
#endif

  i2s_set_pin(I2S_PORT, &pin_config);

  //FIXME: There is a known issue with esp-idf and sampling rates, see:
  //       https://github.com/espressif/esp-idf/issues/2634
  //       In the meantime, the below line seems to set sampling rate at ~47999.992Hz
  //       fifs_req=24576000, sdm0=149, sdm1=212, sdm2=5, odir=2 -> fifs_reached=24575996
  //NOTE:  This seems to be fixed in ESP32 Arduino 1.0.4, esp-idf 3.2
  //       Should be safe to remove...
  //#include <soc/rtc.h>
  //rtc_clk_apll_enable(1, 149, 212, 5, 2);
}

void initMicrophone() {
  mic_i2s_init();
  // Discard first block, microphone may have startup time (i.e. INMP441 up to 83ms)
  i2s_read(I2S_PORT, &samples, SAMPLES_SHORT * sizeof(int32_t), &bytes_read, portMAX_DELAY);
  // Equivalent to: i2s_read(0, &samples, SAMPLES_SHORT * sizeof(int32_t), &bytes_read, portMAX_DELAY);
}

void readMicrophoneData() {
  // Block and wait for microphone values from I2S
  //
  // Data is moved from DMA buffers to our 'samples' buffer by the driver ISR
  // and when there is requested ammount of data, task is unblocked
  //
  // Note: i2s_read does not care it is writing in float[] buffer, it will write
  //       integer values to the given address, as received from the hardware peripheral.
  i2s_read(I2S_PORT, &samples, SAMPLES_SHORT * sizeof(SAMPLE_T), &bytes_read, portMAX_DELAY);

  // Convert (including shifting) integer microphone values to floats,
  // using the same buffer (assumed sample size is same as size of float),
  // to save a bit of memory
  SAMPLE_T* int_samples = (SAMPLE_T*)&samples;

  for (int i = 0; i < SAMPLES_SHORT; i++) samples[i] = MIC_CONVERT(int_samples[i]);

  // Apply equalization and calculate Z-weighted sum of squares,
  // writes filtered samples back to the same buffer.
  q.sum_sqr_SPL = MIC_EQUALIZER.filter(samples, samples, SAMPLES_SHORT);

  // Apply weighting and calucate weigthed sum of squares
  q.sum_sqr_weighted = WEIGHTING.filter(samples, samples, SAMPLES_SHORT);

  // Calculate dB values relative to MIC_REF_AMPL and adjust for microphone reference
  double short_RMS = sqrt(double(q.sum_sqr_SPL) / SAMPLES_SHORT);
  double short_SPL_dB = MIC_OFFSET_DB + MIC_REF_DB + 20 * log10(short_RMS / MIC_REF_AMPL);

  // In case of acoustic overload or below noise floor measurement, report infinty Leq value
  if (short_SPL_dB > MIC_OVERLOAD_DB) {
    Leq_sum_sqr = MIC_OVERLOAD_DB;
  } else if (isnan(short_SPL_dB) || (short_SPL_dB < MIC_NOISE_DB)) {
    Leq_sum_sqr = MIC_NOISE_DB;
  }

  // Accumulate Leq sum
  Leq_sum_sqr += q.sum_sqr_weighted;
  Leq_samples += SAMPLES_SHORT;

  // When we gather enough samples, calculate new Leq value
  if (Leq_samples >= SAMPLE_RATE * LEQ_PERIOD) {
    double Leq_RMS = sqrt(Leq_sum_sqr / Leq_samples);
    Leq_dB = MIC_OFFSET_DB + MIC_REF_DB + 20 * log10(Leq_RMS / MIC_REF_AMPL);
    Leq_sum_sqr = 0;
    Leq_samples = 0;

    // Serial.printf("Calculated dB: %.1fdB\n", Leq_dB);
    printReadingToConsole(Leq_dB);

    if (Leq_dB < minReading) minReading = Leq_dB;
    if (Leq_dB > maxReading) maxReading = Leq_dB;
    sumReadings += Leq_dB;
    numberOfReadings++;
  }
}

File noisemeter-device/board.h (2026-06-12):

/// @file
/// @brief Pre-defined hardware configurations
///
/// Each supported board must have a defined section here to specify the
/// hardware pins and peripherals being used. Selecting a board for
/// compilation is done through PlatformIO.
/* noisemeter-device - Firmware for CivicTechTO's Noisemeter Device
 * Copyright (C) 2024  Clyne Sullivan, Nick Barnard
 *
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
 * You should have received a copy of the GNU General Public License
 * along with this program.  If not, see <https://www.gnu.org/licenses/>.
 */
#ifndef BOARD_H
#define BOARD_H

#undef SERIAL

#if defined(BOARD_REV4)

/** Pin number for the board's LED. */
#define PIN_LED1    GPIO_NUM_17
/** Pin number for the board's factory reset button. */
#define PIN_BUTTON  GPIO_NUM_15
/** Pin number for the microphone's clock pin. */
#define I2S_SCK     GPIO_NUM_5
/** Pin number for the microphone's data out pin. */
#define I2S_SD      GPIO_NUM_6

/** I2S peripheral instance to be used. */
#define I2S_PORT    I2S_NUM_0
/** Channel format for the incoming microphone data.
 * There is only one microphone, so this must be either only left or right. */
#define I2S_FORMAT  I2S_CHANNEL_FMT_ONLY_LEFT

/** Serial instance to use for logging output. */
#define SERIAL      USBSerial

#define USE_MIC_IM64D130A

#include <HWCDC.h>
extern HWCDC USBSerial;

#elif defined(BOARD_REV123)

#define PIN_LED1    GPIO_NUM_0
#define PIN_BUTTON  GPIO_NUM_1
#define I2S_WS      GPIO_NUM_4
#define I2S_SCK     GPIO_NUM_5
#define I2S_SD      GPIO_NUM_6
#define I2S_PORT    I2S_NUM_0
#define I2S_FORMAT  I2S_CHANNEL_FMT_ONLY_LEFT
#define SERIAL      USBSerial

#define USE_MIC_SPH0645

#include <HWCDC.h>
extern HWCDC USBSerial;

#elif defined(BOARD_BREADBOARD)

#define PIN_LED1    GPIO_NUM_36 // random choice
#define PIN_LED2    GPIO_NUM_39 // random choice
#define PIN_BUTTON  GPIO_NUM_5
#define I2S_WS      GPIO_NUM_18
#define I2S_SCK     GPIO_NUM_23
#define I2S_SD      GPIO_NUM_19
#define I2S_PORT    I2S_NUM_0
#define I2S_FORMAT  I2S_CHANNEL_FMT_ONLY_RIGHT
#define SERIAL      Serial

#define USE_MIC_SPH0645

#else
#error "Please select a board from the list in board.h!"
#endif

#endif // BOARD_H

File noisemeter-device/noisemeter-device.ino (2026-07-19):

/// @file
/// @brief Main firmware code
/* noisemeter-device - Firmware for CivicTechTO's Noisemeter Device
 * Copyright (C) 2024  Clyne Sullivan, Nick Barnard
 *
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
 * You should have received a copy of the GNU General Public License
 * along with this program.  If not, see <https://www.gnu.org/licenses/>.
 */
#include <WiFi.h>
#include <esp_efuse.h>
#include <esp_efuse_table.h>

#include "access-point.h"
#include "api.h"
#include "blinker.h"
#include "board.h"
#include "data-packet.h"
#include "spl-meter.h"
#include "storage.h"
#include "ota-update.h"
#include "UUID/UUID.h"

#include <cstdint>
#include <list>
#include <optional>

#if defined(BOARD_REV4) || defined(BOARD_REV123)
HWCDC USBSerial;
#endif

/** Maximum number of seconds to wait for successful WiFi connection. */
constexpr auto WIFI_CONNECT_TIMEOUT_SEC = MIN_TO_SEC(2);
/** Maximum number of seconds to try making new WiFi connection. */
constexpr auto WIFI_NEW_CONNECT_TIMEOUT_SEC = 20;
/** Specifies how frequently to check for OTA updates from our server. */
constexpr auto OTA_INTERVAL_SEC = HR_TO_SEC(24);
/** Maximum number of data packets to retain when WiFi is unavailable. */
constexpr auto MAX_SAVED_PACKETS = 7 * 24 * 60;

static API::DeviceConfig config;

static int uploadCountdown = 0;
static int otaCountdown = 0; // zero to force check on first upload

/** Storage instance to manage stored credentials. */
static Storage Creds;
/** Linked list of completed data packets.
 * This list should only grow if WiFi is unavailable. */
static std::list<DataPacket> packets;
/** Track first measurement upload so diagnostics can be sent/included. */
static bool firstSend;

/**
 * Outputs the given decibel reading over serial.
 * @param reading The decibel reading to display
 */
void printReadingToConsole(double reading);

void otaUpdateCheck(API&);

/**
 * Callback for AccessPoint that verifies credentials and attempts registration.
 * @param ssid The name of the network to connect to
 * @param psk The named network's password
 * @param email The user's email for registration, or leave empty
 * @return An error message if not successful
 */
std::optional<const char *> saveNetworkCreds(String ssid, String psk, String email);

/**
 * Generates a UUID that is unique to the hardware running this firmware.
 * @return A device-unique UUID object
 */
UUID buildDeviceId();

/**
 * Attempt to establish a WiFi connected using the stored credentials.
 * @param mode WiFi mode to run in (e.g. WIFI_STA or WIFI_AP_STA)
 * @param timout Connection timeout in seconds
 * @return Zero on success or a negative number on failure
 */
int tryWifiConnection(wifi_mode_t mode = WIFI_STA, int timeout = WIFI_CONNECT_TIMEOUT_SEC);

static TaskHandle_t measurementTask;
static void measurementHandler(void *);

/**
 * Firmware entry point and initialization routine.
 */
void setup()
{
  pinMode(PIN_LED1, OUTPUT);
  digitalWrite(PIN_LED1, LOW);

  // Grounding this pin (e.g. with a button) will force access open to start.
  // Useful as a "reset" button to overwrite currently saved credentials.
  pinMode(PIN_BUTTON, INPUT_PULLUP);

  SERIAL.begin(115200);

  if (xTaskCreate(measurementHandler, "dba", 2048, nullptr,
    uxTaskPriorityGet(nullptr), &measurementTask) == pdFAIL)
  {
    SERIAL.println("xTaskCreate failed!");
  }

  delay(2000);
  SERIAL.println();
  SERIAL.print("Noisemeter ");
  SERIAL.print(NOISEMETER_VERSION);
  SERIAL.print(' ');
  SERIAL.println(buildDeviceId());
  SERIAL.println("Initializing...");

  Creds.begin(buildDeviceId());
#ifdef STORAGE_SHOW_CREDENTIALS
  SERIAL.println(Creds);
#endif

#ifndef UPLOAD_DISABLED
  bool isAPNeeded = false;

  if (!digitalRead(PIN_BUTTON) || !Creds.valid()) {
    SERIAL.print("Erasing stored credentials...");
    Creds.clear();
    SERIAL.println(" done.");

    isAPNeeded = true;
  } else if (Creds.get(Storage::Entry::Token)[0] == '\0') {
    isAPNeeded = true;
  } else if (tryWifiConnection(WIFI_STA) < 0) {
    isAPNeeded = true;
  } else if (Timestamp::synchronize() < 0) {
    isAPNeeded = true;
  }

  // Run the access point if it is requested or if there are no valid credentials.
  if (isAPNeeded) {
    AccessPoint ap (saveNetworkCreds);
    Blinker bl (500);

    ap.run();

    // Access point timed out: power off.
    SERIAL.println("No connections. Power off.");
    delay(500);
    esp_sleep_disable_wakeup_source(ESP_SLEEP_WAKEUP_ALL);
    esp_deep_sleep_start();
  }

  firstSend = true;

  SERIAL.println("Connected to the WiFi network.");
  SERIAL.print("Local ESP32 IP: ");
  SERIAL.println(WiFi.localIP());
  SERIAL.print("Current time: ");
  SERIAL.println(Timestamp());

  API api (buildDeviceId(), Creds.get(Storage::Entry::Token));
  const auto deviceConfig = api.getDeviceConfig();
  if (deviceConfig) {
    config = *deviceConfig;
    uploadCountdown = config.sendFrequency;
  } else {
    uploadCountdown = MIN_TO_SEC(5); // 5 min default
  }
#endif // !UPLOAD_DISABLED

  digitalWrite(PIN_LED1, HIGH);
}

void loop()
{
  auto lastWake = xTaskGetTickCount();

  auto readyCount = packets.size();
  if (readyCount == MAX_SAVED_PACKETS) {
    SERIAL.println("Discarded a packet!");
    packets.pop_back();
  }

  // Timestamp current packet, then immediately create new packet for ongoing
  // samples to feed into.
  packets.front().timestamp = Timestamp();
  packets.emplace_front();

#ifndef UPLOAD_DISABLED
  otaCountdown -= config.measurementFrequency;
  uploadCountdown -= config.measurementFrequency;

  if (uploadCountdown <= 0) {
    uploadCountdown = config.sendFrequency;

    if (WiFi.status() != WL_CONNECTED) {
      SERIAL.println("Attempting WiFi reconnect...");
      WiFi.reconnect();
      delay(5000);
    }

    if (WiFi.status() == WL_CONNECTED) {
      API api (buildDeviceId(), Creds.get(Storage::Entry::Token));
      std::optional<String> deviceLastModified;

      if (firstSend) {
        deviceLastModified = api.sendMeasurementWithDiagnostics(
          packets.back(), NOISEMETER_VERSION, String(millis() / 1000));

        if (deviceLastModified) {
          packets.pop_back();
          readyCount--;
          firstSend = false;
        }
      }

      if (readyCount == 1) {
        deviceLastModified = api.sendMeasurement(packets.back());
        if (deviceLastModified) {
          packets.pop_back();
          readyCount = 0;
        }
      } else {
        deviceLastModified = api.sendMeasurements(packets, ++packets.cbegin());
        if (deviceLastModified) {
          packets.erase(++packets.cbegin(), packets.cend());
          readyCount = 0;
        }
      }

      if (deviceLastModified && *deviceLastModified > config.timestamp) {
        // New device config on server - fetch and update
        const auto deviceConfig = api.getDeviceConfig();
        if (deviceConfig)
          config = *deviceConfig;
      }

      if (readyCount > 0) {
        SERIAL.print(readyCount);
        SERIAL.println(" packets still need to be sent!");
      }
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

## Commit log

2023-12-31 Add Raspberry Pi code
2023-12-31 Add ESP32 pinout & connections table
2023-12-31 Add v1 for esp32
2023-12-31 Add HTTPS example for ESP32
2024-01-01 Add HTTPS upload to ESP32 v1
2024-01-01 Add mic reading functionality to ESP32 v1
2024-01-01 Add more pin info for ESP32 Readme
2024-01-03 Fix upload data shape
    [proj-noisemeter-device-esp32-v1.ino]
2024-01-11 add kicad files
    [noisemeter.kicad_pcb, noisemeter.kicad_sch]
2024-01-19 initial port to pcb
2024-01-21 status LEDs; SERIAL definition
2024-01-24 move bringup to esp32c3 folder
    [noisemeter.kicad_pcb, noisemeter.kicad_sch]
2024-01-24 bring back esp32 implementation
2024-01-30 schematic/layout draft
    [noisemeter.kicad_pcb, noisemeter.kicad_sch]
2024-02-04 redesign for 1551SFL case
    [noisemeter.kicad_pcb, noisemeter.kicad_sch]
2024-02-04 restore pcb-rev1 hw files
    [noisemeter.kicad_pcb, noisemeter.kicad_sch]
2024-02-05 add rev2 files
    [nmeter_cased.FCStd, noisemeter.kicad_pcb, noisemeter.kicad_sch]
2024-02-07 finalize rev2 design
    [noisemeter.kicad_pcb, noisemeter.kicad_sch]
2024-02-16 final edits and bom changes
    [noisemeter.kicad_pcb, noisemeter.kicad_sch]
2024-02-16 rename pcb-rev1 to esp32-pcb
    pcb rev2 is identical, let's use a common name
2024-02-16 actions: switch to node 20
2024-02-18 comment out UUID code
    Overwrites checksum causing WiFi creds check to always fail
    [noisemeter-device.ino]
2024-02-24 move config.h include to board.h
    fixes arduino builds
    [board.h, noisemeter-device.ino]
2024-03-05 batch uploads in case WiFi is lost
2024-03-06 simplified packet processing; timestamp replaces millis
    [noisemeter-device.ino]
2024-03-11 add pcb-rev2 image
2024-03-24 only enable OTA for PCBs
2024-03-26 fixed UUID for device ID based on MAC
    [noisemeter-device.ino]
2024-03-26 add wifi timeout and fix empty ssid check
    [noisemeter-device.ino]
2024-03-26 blink led during access point
2024-04-01 fix wifi connected typo
    Really should have caught this before pushing, ugh.
    [noisemeter-device.ino]
2024-04-01 fix debug print order
    [noisemeter-device.ino]
2024-04-13 member cleanup and replace defines with constexpr
    [spl-meter.cpp]
2024-05-19 register device while in AP mode
2024-05-19 timeout tweaks; poweroff on no AP connection
2024-05-21 wip: ota signing
    [nmpartitions.csv]
2024-05-23 fix signed ota; dummy key for Action
    [ota-update.cpp]
2024-05-28 remove arduino ide support
2024-07-02 misc fixes
    Keep extra storage entry so checksum is not ruined; clear API token if re-registering; blink faster for multi-packet send
    [noisemeter-device.ino]
2024-07-19 Switched back to println for console readings.
2024-07-20 fix token validity checks
    [noisemeter-device.ino]
2024-09-22 add draft rev3 files
    [noisemeter.kicad_pcb, noisemeter.kicad_sch]
2024-09-22 minor schematic fixes
    [noisemeter.kicad_pcb, noisemeter.kicad_sch]
2024-10-08 cleaning up layout
    [noisemeter.kicad_pcb, noisemeter.kicad_sch]
2024-10-19 add pcb render
2024-10-27 pcb-rev3: add freecad file
    [tracket.FCStd]
2025-03-29 use X-Tracket-Device header
2025-10-26 esp32s3 and pdm mic proof-of-concept
2025-12-06 add rev4 hardware files
    [ESP32-S3-MINI-1-N8.STEP, PG-TLGA-5-2_Z8B00234305_V05_3D.stp, noisemeter.kicad_pcb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]
2025-12-14 remove ci build for esp32-breadboard
2026-01-10 finalize rev4 hardware
    [noisemeter.kicad_pcb, noisemeter.kicad_sch]
2026-01-17 firmware working on rev4 boards
2026-06-12 refactor: keep support for earlier revs
    Changed board definitions; ported older revs to latest I2S library; force older revs to only accept pre-v0.4 updates
2026-06-29 data point every minute; ota separation for rev4; access point fixes
    New access point passkey!
    [noisemeter-device.ino]
2026-07-19 support device config endpoint

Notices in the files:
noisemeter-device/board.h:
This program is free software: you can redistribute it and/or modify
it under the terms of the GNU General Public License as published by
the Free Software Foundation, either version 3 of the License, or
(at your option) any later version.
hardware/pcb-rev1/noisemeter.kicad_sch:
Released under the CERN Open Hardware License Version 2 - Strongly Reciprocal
